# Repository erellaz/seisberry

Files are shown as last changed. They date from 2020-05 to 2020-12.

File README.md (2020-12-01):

# Seisberry
Code for Raspberry Pi seismograph, 3 components

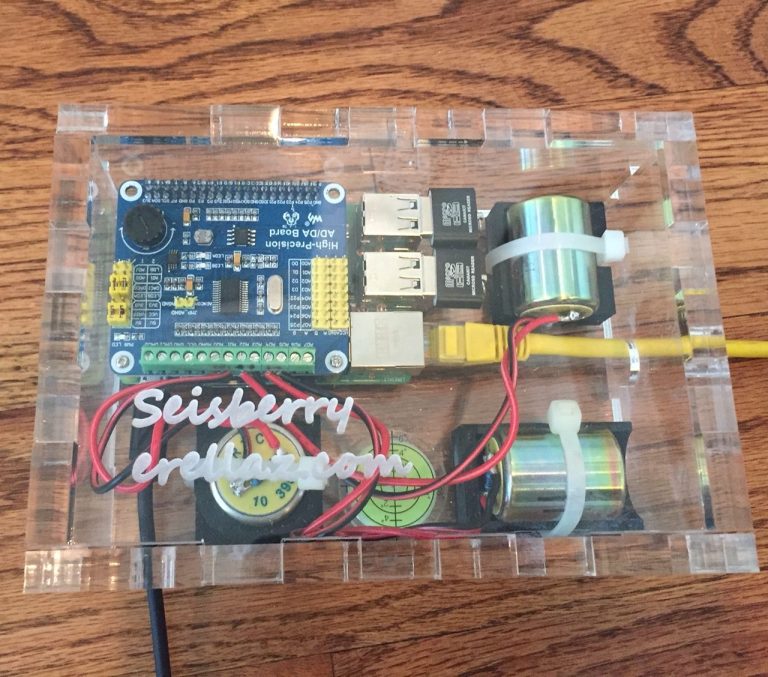
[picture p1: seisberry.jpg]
Seisberry


## Eager to start? Follow the fast build guide.
This page should get you up and running in 30 to 60 minutes, using an image of the Seisberry, with everything ready.
No need to mess with compiling or running codes if you don't want to. Just connect the parts, set the jumpers and start recording.
https://erellaz.com/blog/seisberry/seisberry-fast-build/

## Running on the Raspberry
The python code prefixed Pi_ are optimized to run within the 32 bit memory limits of the Raspberry hardware.
The rest of the code is optimized for 64 bit systems, like a desktop with ample memory.

## C Code
For the C code doing the actual sampling, see: 
https://github.com/erellaz/RaspberryPi-seismograph/blob/master/README.md

## Help and install guide
Visit http://erellaz.com/seisberry

Read the Jupiter Notebook provided with the project. I spent quite a long time building this documentation, and it should help other users  dramatically cut time and avoid frustration building their own seisberry. 
https://github.com/erellaz/seisberry/blob/master/seisberry.ipynb

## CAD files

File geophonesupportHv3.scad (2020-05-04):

//Geophone support RTC 10Hz

//Dimensions-------------------------------------------------
//All in mm

// Geophone dimensions
hg=34;   //height
dg=26;  //diameter 

// support
bases=50;
hs=7;
w=9;
e=5;

//holes
dh=3;
th=27;

//groove
gw=6;
gd=5;
gdd=3;
//--------------------------------------------------------------
$fn=100;//resolution

module Make_body() {
difference(){
union(){
translate([0,0,hs/2]) cube([bases,bases,hs],center=true);
translate([0,0,dg/4]) cube([bases-20,bases,dg/2],center=true);
}
translate([0,-11,e+dg/2])  rotate([90,0,0]) cylinder(h=hg+30,d=dg,center=true);
}
}
module Make_holes() {
union(){
rotate([0,0,45])translate([th,0,0]) cylinder(h=3*hs,d=dh,center=true);
rotate([0,0,135])translate([th,0,0]) cylinder(h=3*hs,d=dh,center=true);
rotate([0,0,225])translate([th,0,0]) cylinder(h=3*hs,d=dh,center=true);
rotate([0,0,315])translate([th,0,0]) cylinder(h=3*hs,d=dh,center=true);
}}

module Make_groove() {
    union(){
    cube([100,gw,gd],center=true);
    //rotate([0,0,90]) cube([100,gw,gd],center=true);
}}

module Make_groove_holes(){
   union(){
    translate([(gdd+bases)/2-10,0,0])rotate([0,90,0])cube([100,gw,gdd],center=true);
    translate([-(gdd+bases)/2+10,0,0])rotate([0,90,0])cube([100,gw,gdd],center=true);
}}


/*
color( "blue", 1.0 ) {
Make_groove_holes();
}
*/

difference(){
difference(){
difference(){
Make_body();
Make_holes();
}
Make_groove();
}
Make_groove_holes();
}

/*
color( "green", 1.0 ) {
translate([0,0,e+hg/2]) cylinder(h=hg,d=dg,center=true);
}
*/

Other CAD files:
geophonesupportHv4.scad
geophonesupportVv3.scad
geophonesupportVv4.scad
Pi_support.scad

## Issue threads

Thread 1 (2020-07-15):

Output unit of measurement

tommy15979, 2020-07-15:
Hi,
I just completed your awesome project.
Now i can register all data on TXT, but i don't understand if the file contains the Voltage of geophone or, in some way, you convert this voltage to mm/s or m/s.
In this case, i don't know how to modify main.c to consider geophone sensitivity (V/cm/s).

erellaz, 2020-07-17:
Glad you made one!
To your question:
- the geophone manufacturer will provide you with a spec sheet showing the sensitivity in v/m/s. For example on the sheet linked below I read 20V per m/s in the frequency range where the sensitivity remains a constant (that is from 10hz to Nyquist frequency).
https://rtclark.com/wp-content/uploads/2015/10/RTC-10hz-395-Spec-Curve-Email.pdf
- the C program has 2 gains: one hardware gain passed to the board, and one software gain, used to multiply the value delivered by the board before writing to the text file.

Therefore the products of the software gain by the hardware gain by the geophone manufacturer sensitivity gives you the scale factor between the value written out by the program in the text file and the velocity measured by the geophone.

Here is how to QC and calibrate this. Replace the geophone by a known calibrated constant voltage of a few millivolts (or the signal generator of an oscilloscope), and make sure what you record in the text file has exactly the value of the input voltage as delivered by your calibrated source. If it does, introduce the geophone sensitivity in the scale factor and put the geophone back.

I will leave this ticket open until I have rigorously verified the gain application in the C program and on the board -or if you confirm the problem is solved on your side.

tommy15979, 2020-07-17:
Ok.
For example, my Geophone specs are (LGT-20D10):
http://www.longetequ.com/geophone/5.htm
So, making the product = 1, I can modify parameters file using:
Ampgain=64
Numgain=0.078125
In this case 64x0,2x0.078125 = 1

then I can try to calibrate it with oscilloscope!

erellaz, 2020-07-17:
Yes, I think so. I have not tested it yet though.

I realize what I need is allow the user to enter the geophone sensitivity (straight from sensor manufacturer specs) in the param file, and optionally the pre-amplifier gain (for those who want to fine tune dynamic and over-scaling). Then the program should automatically calculate the electronic gain so the result is always calibrated in m/s.

I will do that and test it with the various geophones I have, but that make take a little time.

tommy15979, 2020-07-17:
Unfortunately i am able only to develop windows software (vb/c#). I think that a userform would be useful. For example, to start/stop logging and to set param file

tommy15979, 2020-07-23:
Hi, have you tried to modify config file? If you want i can do some test

erellaz, 2020-08-23:
BTW, I also added a GUI:
https://github.com/erellaz/seisberry/blob/master/SeismographGUI.py

erellaz, 2020-08-31:
Here is a step by step tutorial to do the calibration and test the instrument with an oscilloscope.
This was fully tested on 8/30/2020, and it works.
https://erellaz.com/blog/seisberry/calibrating-a-seisberry/

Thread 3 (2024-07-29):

Feature Request: Send data over UDP for use with rsudp for real time data viewing

Trent-l, 2024-07-29:
Hi there, recently built a seisberry and am very happy with the form and simplicity of it. The only downside I'm finding is the inflexibility of viewing and processing the data. After some research I happened across the open source rsudp software intended for use with the raspberry shake https://github.com/raspishake/rsudp. I have very limited expertise in programming, but it seems like it would be relatively straightforward to send the data from the seisberry over UDP in the format that the rsudp software is expecting. The necessities of the datastream are here: https://manual.raspberryshake.org/udp.html

Individual data packets are sent to port 8888 on the Shake Pi computer by default. The output format is straightforward:

        Each data packet contains data for a single channel only
        Entire data packet is wrapped with open and closing braces: { }
        All fields are separated by a comma
        First element defines the channel name - string in single quotes
        Second element defines the timestamp, in epoch seconds, down to milliseconds, of the first data point - float
        All remaining elements are the data points themselves - integer

 ...and here is an example packet:

    {'SHZ', 1507760140.530, 614, 916, 1095, 1156, 839, 923, 861, 856, 861, 789, 568, 823, 965, 788, 835, 991, 1028, 1225, 1142, 828, 682, 635, 771, 978, 834, 1167, 1116, 888, 627, 564, 944, 994, 780, 652, 811, 915, 832, 1134, 1020, 594, 756, 782, 748, 810, 864, 936, 977, 1014, 676, 502}

If you could at least point me to how to parse the raw data coming off the ad/da board I can probably bodge something together to send the packets as needed.

Thanks!

erellaz, 2024-07-29:
I will look into it. Also want to do a new 32 bit version of the seismograph, and update the Linux OS...

Trent-l, 2024-07-29:
That would be fantastic! Very excited to be able to view the live data. If there's anything I can do to help out let me know. Also, here is the 3d printed platform we designed. Please feel free to link to it or upload the files directly to the Seisberry page.

https://github.com/Trent-l/Seisberry-3d-printed-platform

erellaz, 2024-07-30:
Thanks, I added your mount to the project website. This is an excellent
alternative to the box

Cheers.

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

--
Guillaume S. RICHARD

Trent-l, 2025-03-06:
Hey! Any update on this? Our Seisberry stopped collecting data a while ago and I had been holding off reinstalling the OS.

minnican, 2025-03-12:
This is a great project and I've just finished building it. Thanks. I'm looking forward to the new edition that was teased last year. Would love real-time data plotting too but for a Pi 3B it seems a bit too resource intensive. I can't code but AI, especially Grok, has created a script that allowed me to plot "live data" for each hour.

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

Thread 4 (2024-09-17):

SSD storage instead of microSD?

astrotater, 2024-09-17:
Erellaz, you mention in the hardware section of the seisberry that "one internal micro SD for the Linux OS; two external Micro SD memory to store the seismic data in raw format and Miniseed / Segy" are needed.
Is it possible to instead use an SSD drive instead of 3 separate microSD cards?
Either a USB SATA SSD with a Pi3b or a new Pi5 with an NVME?

erellaz, 2024-09-18:
I have used SSD for data storage, no problem. Anything you can NFS mount on the Raspberry will do. If you wanted to mount a network storage, that would work.
Now I think the Raspberry OS needs to be on the one internal SD card of the Raspberry, it is at least the simplest way to install the OS.

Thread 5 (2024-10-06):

A couple of questions as I build this with my daughter

astrotater, 2024-10-06:
My daughter was learning about earthquakes and seismographs in school, which inspired me to build this with her.
I have never worked with a geophone before.
You mention a 395-ohm geophone resistor with a 1000-ohm shunt. Could you explain that in a little more detail?
I have 2 horizontal and 1 vertical 10Hz GD-10J geophones I ordered off Aliexpress. Now that I have them, I'm not sure what to do next in regards to the resistor and shunt before I hook them up to the A/D board.

erellaz, 2024-10-06:
Resistor is optional, to change the resonance frequency of the phone. The manufacturer provides curves with the frequency in x and the sensitivity of the phone in y. Usually you have a couple of curves, one in "open circuit", ie no resitor, and a few with various resistors.  The resistor is the shunt. You do not want to connect the 2 pads of the phone together. Here is how it should look once the shunt resistor is installed:
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

erellaz, 2024-10-06:
And here is an example of response, without the resistor (red curve) and with a resistor (green curve).
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

erellaz, 2024-10-06:
Then, whether or not you use a resistor, connect a wire to each pad, and connect them to the ADC board..

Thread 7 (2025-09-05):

can't get quickstart img to take on rasp 3b+

freitz, 2025-09-05:
can apply other images (64-bit rasp pi OS) fine but the one from the quickstart gives me 4 slow flashes, 7 fast, have tried 16 and 32 Gb SD cards.

have other people used the posted img successfully?

(this probably isn't the place to ask but couldn't find another avenue of contact)

robbie-kieffer, 2025-09-09:
yes, though it did take some digging...  It's a firmware vs software conflict, since this in an older build and your hardware is probably newer...

Go to: https://github.com/raspberrypi/firmware/tree/master/boot

Grab the start*.elf files (there are eight of them) and copy them to your SD card (replacing the ones there).

Theoretically, it'll boot right up (though mine isn't currently....I cracked my SD card and am having to start over...)

freitz, 2025-09-10:
aha thanks yes that got me all the way to the gui desktop!

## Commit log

2020-04-26 Optimized to run on the Raspberry Pi V2.0
2020-04-28 Fixed the start date of the trace, external event plotting correctly now on day plots.
2020-05-04 OpenSCAD geophone supports for 3D printing.
    Fully parametric.
    [geophonesupportHv3.scad, geophonesupportVv3.scad]
2020-06-07 Smaller geophone supports
    [Pi_support.scad, geophonesupportHv4.scad, geophonesupportVv4.scad]
